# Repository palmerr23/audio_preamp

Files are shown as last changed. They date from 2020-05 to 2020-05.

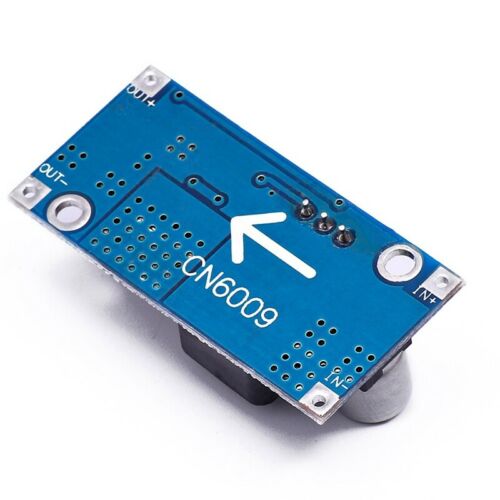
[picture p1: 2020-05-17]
cn6009 bottom.jpg

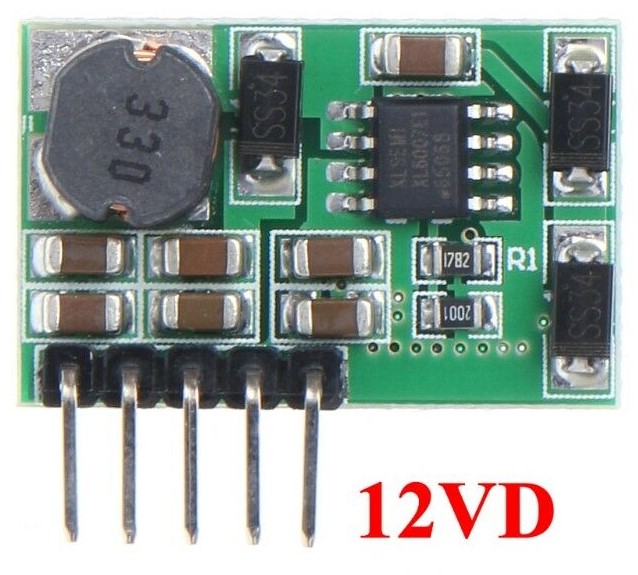
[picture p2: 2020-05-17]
pos neg reg top.jpg

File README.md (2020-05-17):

# audio_preamp
pro grade dual mic-instrument preamp runs off 5V

Designed to complement the audio ADC boards such as the Teensy Audio Board, this pro-grade dual mic/instrument preamp features:
- Single 5v supply operation
- Output aligned to common microcontroller ADC levels (1v RMS, drive loads > 2000 ohms)
- Combo TRS/XLR input jack to save panel space with automatic mic/inst switching 
- 0-20dB gain on instrument channel (1M ohm input impedance)
- Independent +48V phantom power for each mic channel
- THAT1512 mic preamp for optimum performance
- 20 & 40dB switched gain mic channel + 0-20dB gain control (overall gain 20-60dB)

Attached board files are in Eagle 9.0 format

Two 'off the shelf' switching regulator modules power the preamp:
- a +/-15V (often marked DD1718) and a +35 boost regulator based on the XL6007/9 chips. Image files are included, above.

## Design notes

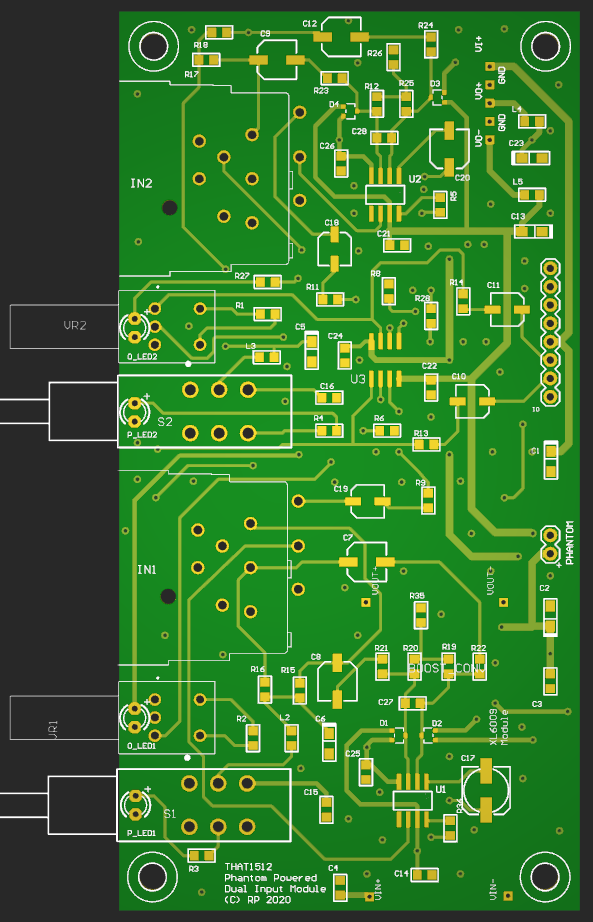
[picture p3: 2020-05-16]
PCB layout.png

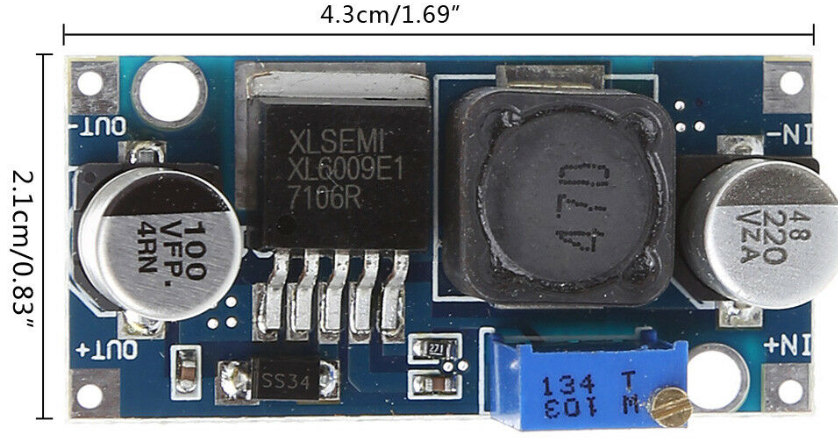
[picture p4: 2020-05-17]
XL6009 module - dims.png

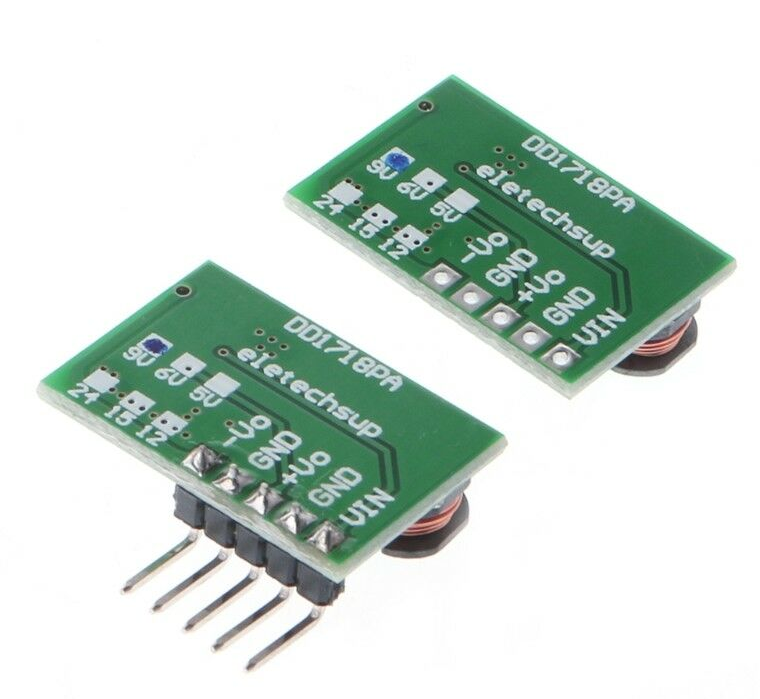
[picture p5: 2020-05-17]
pos neg boost regulator bott.png

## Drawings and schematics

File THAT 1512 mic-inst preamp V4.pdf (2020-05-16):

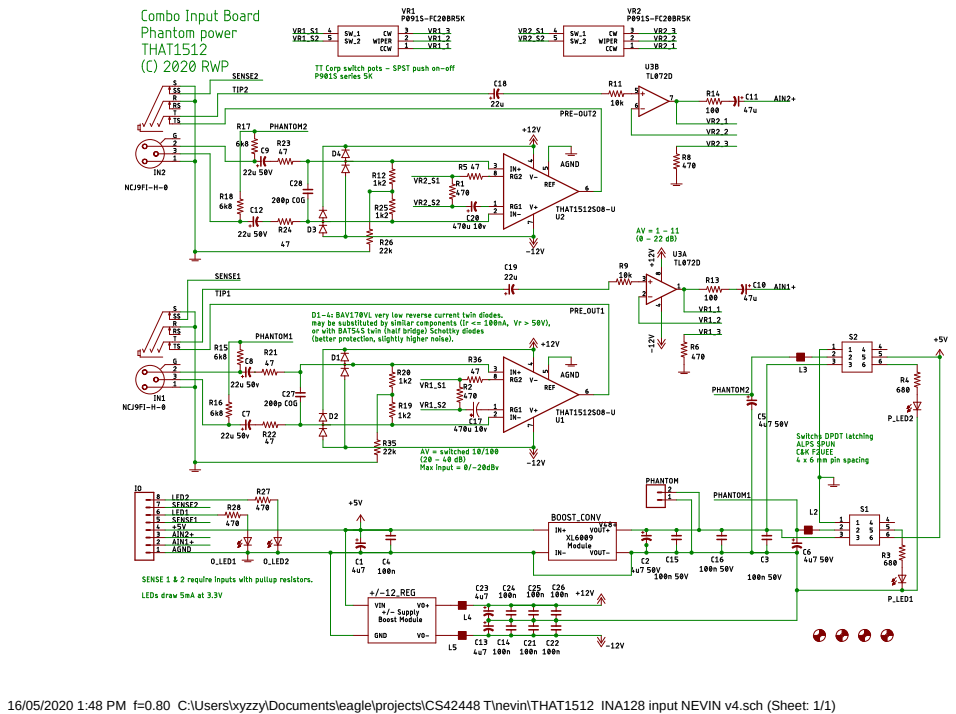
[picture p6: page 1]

16/05/2020 1:48 PM f=0.80 C:\Users\xyzzy\Documents\eagle\projects\CS42448 T\nevin\THAT1512 INA128 input NEVIN v4.sch (Sheet: 1/1)

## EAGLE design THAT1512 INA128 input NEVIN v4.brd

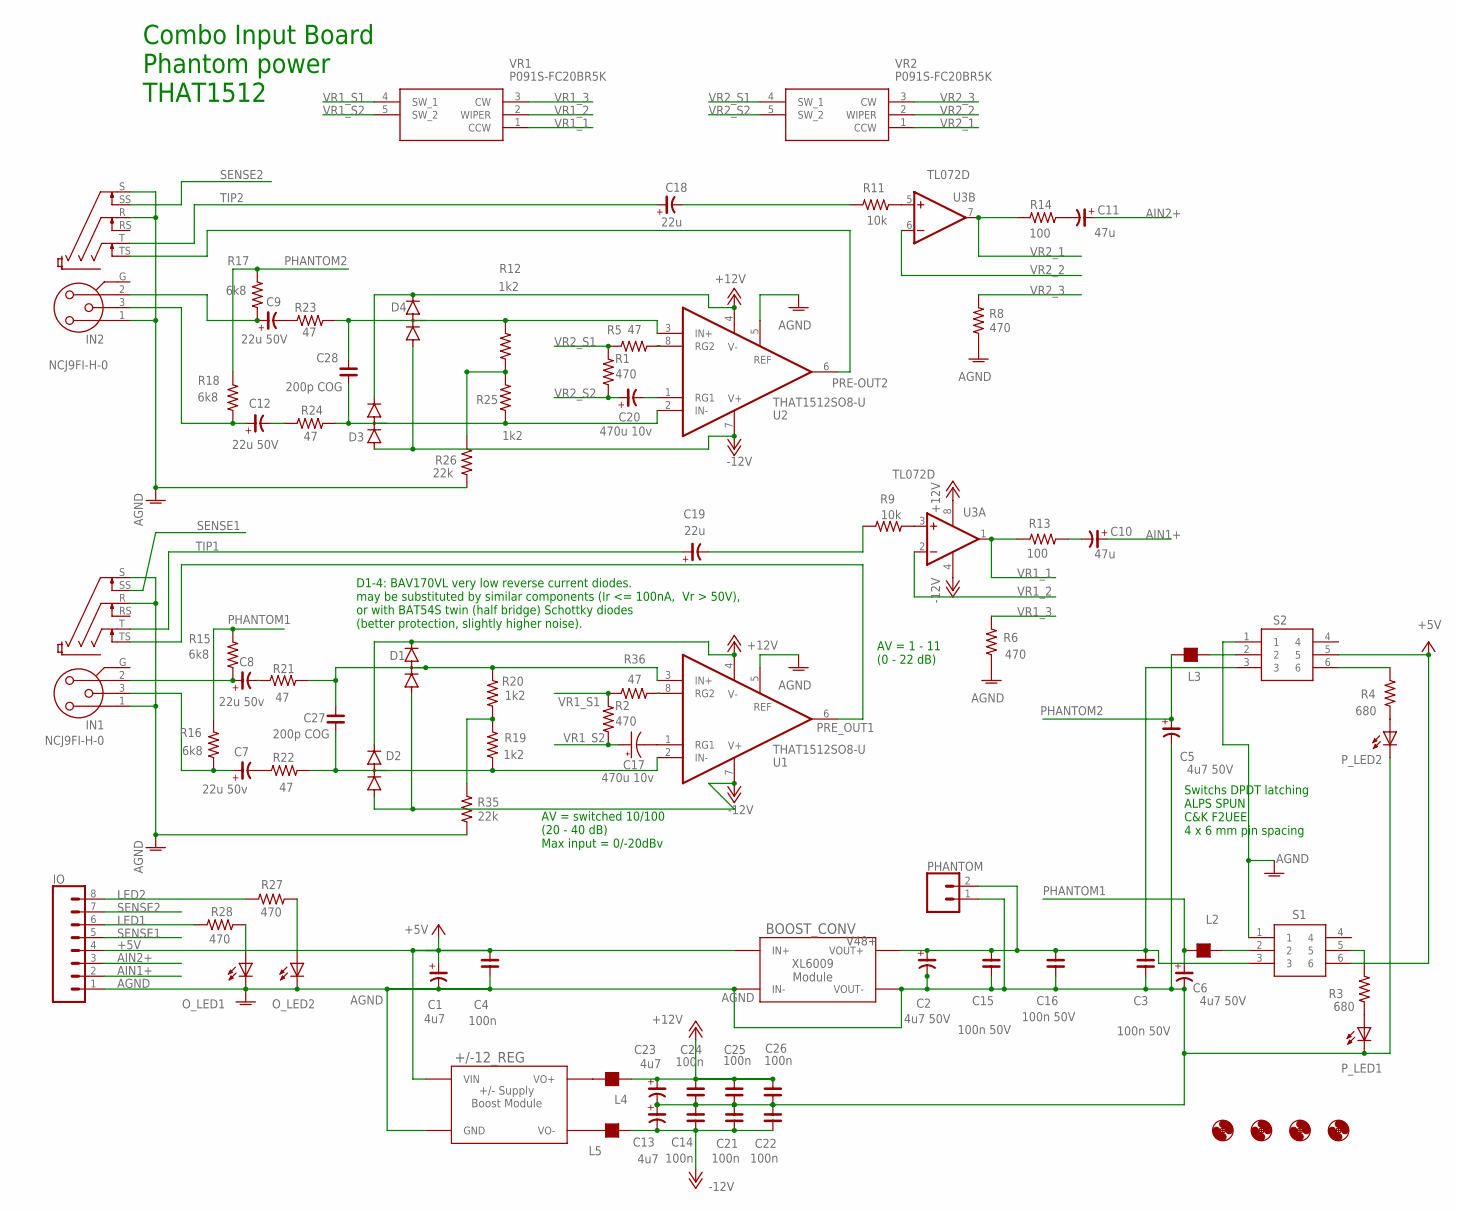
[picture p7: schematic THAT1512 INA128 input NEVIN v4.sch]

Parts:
+/-12_REG: POS_NEG_SUP_MODULE; POS_NEG_SUP_MODULE_F
BOOST_CONV: XL6009_MODULE; XL6009_MODULE_F
C1, C13, C23: 4u7; C3216/T
C2, C5, C6: 4u7 50V; C3216/T
C3, C15, C16: 100n 50V; C0805
C4, C14, C21, C22, C24, C25, C26: 100n; C0805
C7, C8: 22u 50v; CSV-C
C9, C12: 22u 50V; CSV-C
C10, C11: 47u; CSV-B
C17: 470u 10v; 153CLV-0605
C18, C19: 22u; CSV-B
C20: 470u 10v; CSV-C
C27, C28: 200p COG; C0805
D1, D2, D3, D4: HSMS-285C; SOT323
H1, H2, H3, H4: MOUNT-HOLE3.6; 3,6
IN1, IN2: NCJ9FI-H-0; NCJ9FI-H
IO: CONN_08"; 1X08
L2, L3, L4, L5: 150; L0805
O_LED1, O_LED2: LED3MM
PHANTOM: CONN_02; 1X02
P_LED1, P_LED2: LED3MM
R1, R2, R6, R8, R27, R28: 470; R0805
R3, R4: 680; R0805
R5, R21, R22, R23, R24, R36: 47; R0805
R9, R11: 10k; R0805
R12, R19, R20, R25: 1k2; R0805
R13, R14: 100; R0805
R15, R16, R17, R18: 6k8; R0805
R26, R35: 22k; R0805
S1, S2: SPUN191600; SPUN191000
U1, U2: THAT1512SO8-U; SO08
U3: TL072D; SO08
VR1, VR2: P091S-FC20BR5K; P091SFC20BR5K

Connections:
+5V: +/-12_REG.IN+ (VIN), BOOST_CONV.IN+, C1.+, C4.2, IO.4, S1.6, S2.5
+12V: C23.+, C24.2, C25.2, C26.2, D1.2 (C), D2.2 (C), D3.2 (C), D4.2 (C), L4.1, U1.4 (V-), U2.4 (V-), U3.8 (V+)
-12V: C13.-, C14.1, C21.1, C22.1, D1.1 (A), D2.1 (A), D3.1 (A), D4.1 (A), L5.1, U1.7 (V+), U2.7 (V+), U3.4 (V-)
AGND: +/-12_REG.GND, +/-12_REG.GND@1 (GND), BOOST_CONV.IN-, BOOST_CONV.VOUT-, C1.-, C2.-, C3.1, C4.1, C5.-, C6.-, C13.+, C14.2, C15.1, C16.1, C21.2, C22.2, C23.-, C24.1, C25.1, C26.1, IN1.1, IN1.R, IN1.S, IN2.1, IN2.R, IN2.S, IO.1, O_LED1.K (C), O_LED2.K (C), PHANTOM.1, P_LED1.K (C), P_LED2.K (C), R6.2, R8.2, R26.2, R35.2, S1.1, S2.1, U1.5 (REF), U2.5 (REF)
AIN1+: C10.+, IO.2
AIN2+: C11.+, IO.3
LED1: IO.6, R28.2
LED2: IO.8, R27.2
unnamed: C27.2, D1.3 (AC), R20.1, R21.1, U1.3 (IN+)
unnamed: C27.1, D2.3 (AC), R19.2, R22.1, U1.2 (IN-)
unnamed: C28.2, D4.3 (AC), R12.1, R23.1, U2.3 (IN+)
unnamed: R36.2, U1.8 (RG2)
unnamed: L2.1, S1.2
unnamed: P_LED1.A, R3.1
unnamed: L3.1, S2.2
unnamed: R9.1, U3.3 (+IN)
unnamed: P_LED2.A, R4.1
unnamed: R11.1, U3.5 (+IN)
unnamed: R5.2, U2.8 (RG2)
unnamed: R3.2, S1.5
unnamed: R4.2, S2.6
unnamed: C18.-, R11.2
unnamed: +/-12_REG.VO-, L5.2
unnamed: C7.-, R22.2
unnamed: +/-12_REG.VO+, L4.2
unnamed: C11.-, R14.1
unnamed: C10.-, R13.1
unnamed: C7.+, IN1.3, R16.1
unnamed: C8.-, R21.2
unnamed: C8.+, IN1.2, R15.1
unnamed: C9.-, R23.2
unnamed: C12.-, R24.2
unnamed: C9.+, IN2.2, R17.1
unnamed: C12.+, IN2.3, R18.1
unnamed: C28.1, D3.3 (AC), R24.1, R25.2, U2.2 (IN-)
unnamed: C19.-, R9.2
unnamed: O_LED1.A, R28.1
unnamed: O_LED2.A, R27.1
unnamed: R19.1, R20.2, R35.1
unnamed: C17.-, U1.1 (RG1)
unnamed: C20.-, U2.1 (RG1)
unnamed: R12.2, R25.1, R26.1
PHANTOM1: C6.+, L2.2, R15.2, R16.2
PHANTOM2: C5.+, L3.2, R17.2, R18.2
PRE-OUT2: IN2.TS, U2.6 (OUT)
PRE_OUT1: IN1.TS, U1.6 (OUT)
SENSE1: IN1.SS, IO.5
SENSE2: IN2.SS, IO.7
TIP1: C19.+, IN1.T
TIP2: C18.+, IN2.T
V48+: BOOST_CONV.VOUT+, C2.+, C3.2, C15.2, C16.2, PHANTOM.2, S1.3, S2.3
VR1_1: R13.2, U3.1 (OUT), VR1.1 (CCW)
VR1_2: U3.2 (-IN), VR1.2 (WIPER)
VR1_3: R6.1, VR1.3 (CW)
VR1_S1: R2.1, R36.1, VR1.4 (SW_1)
VR1_S2: C17.+, R2.2, VR1.5 (SW_2)
VR2_1: R14.2, U3.7 (OUT), VR2.1 (CCW)
VR2_2: U3.6 (-IN), VR2.2 (WIPER)
VR2_3: R8.1, VR2.3 (CW)
VR2_S1: R1.1, R5.1, VR2.4 (SW_1)
VR2_S2: C20.+, R1.2, VR2.5 (SW_2)

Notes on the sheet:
Combo Input Board Phantom power THAT1512
AV = switched 10/100 (20 - 40 dB) Max input = 0/-20dBv
Switchs DPDT latching ALPS SPUN C&K F2UEE 4 x 6 mm pin spacing
AV = 1 - 11 (0 - 22 dB)
D1-4: BAV170VL very low reverse current diodes. may be substituted by similar components (Ir <= 100nA, Vr > 50V), or with BAT54S twin (half bridge) Schottky diodes (better protection, slightly higher noise).

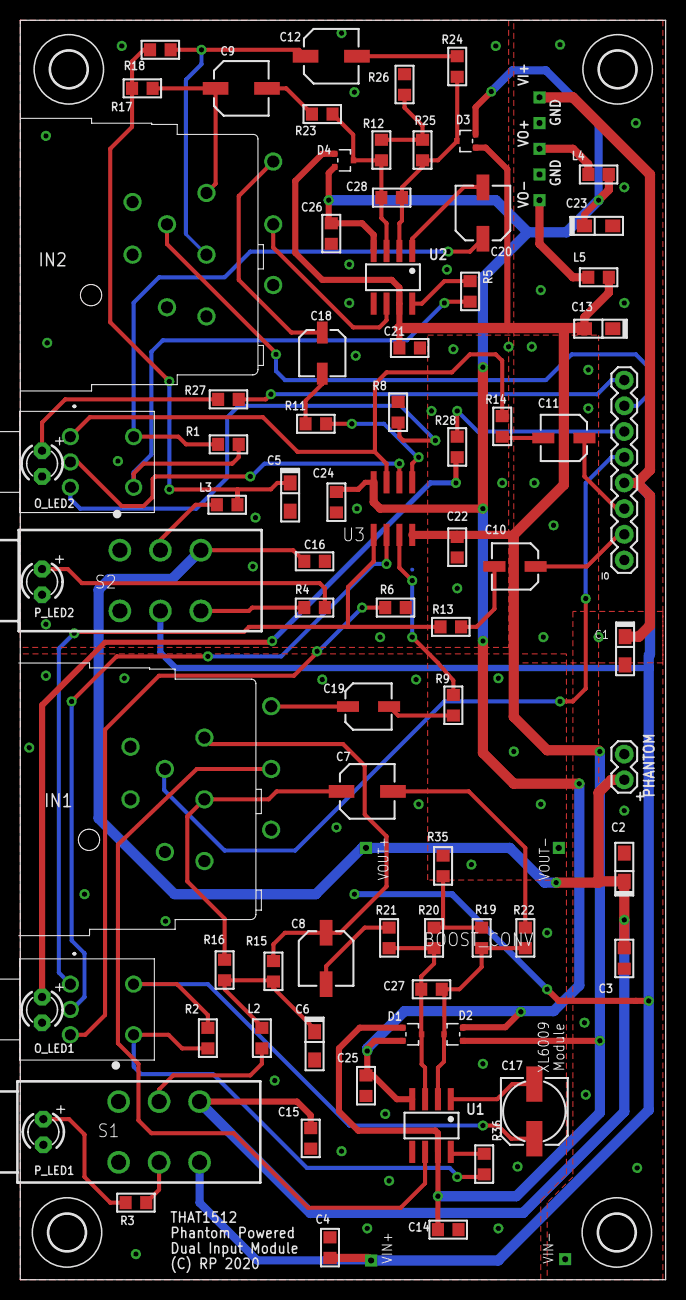
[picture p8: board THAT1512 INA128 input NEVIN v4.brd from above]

Board: 2 copper layers, 63.8 x 124.5 mm, 85 parts (1 on the bottom side), 61 nets.

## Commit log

2020-05-16 Fixed routing
    [THAT1512 INA128 input NEVIN v4.brd]
2020-05-16 improved component placement and labeling
    [THAT1512 INA128 input NEVIN v4.brd]
2020-05-16 Improved notes
    [THAT1512 INA128 input NEVIN v4.sch]
2020-05-17 power supply images

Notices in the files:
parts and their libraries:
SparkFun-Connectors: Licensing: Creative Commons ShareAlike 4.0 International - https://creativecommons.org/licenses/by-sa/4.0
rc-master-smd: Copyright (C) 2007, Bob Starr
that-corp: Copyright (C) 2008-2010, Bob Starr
